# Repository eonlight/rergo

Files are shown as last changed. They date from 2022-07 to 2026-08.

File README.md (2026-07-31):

# rergo v4.0.3

Custom made keyboard using ergopad, ergogen and kicad

# V4

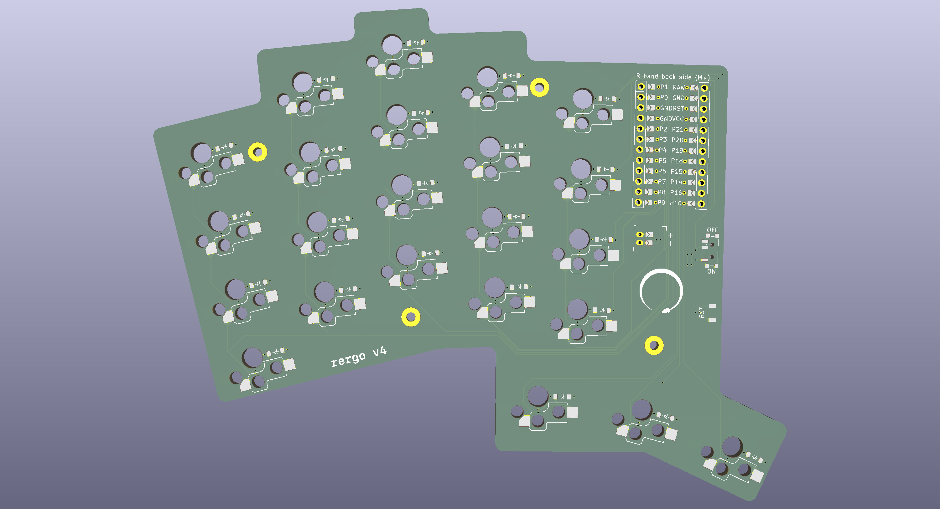
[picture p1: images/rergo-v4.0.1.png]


[rergo v4 design](/designs/v4/)

[rergo v4 kicad](/kicad/v4/)

[rergo v4 zmk config](/zmk-config/v4/)

# V3

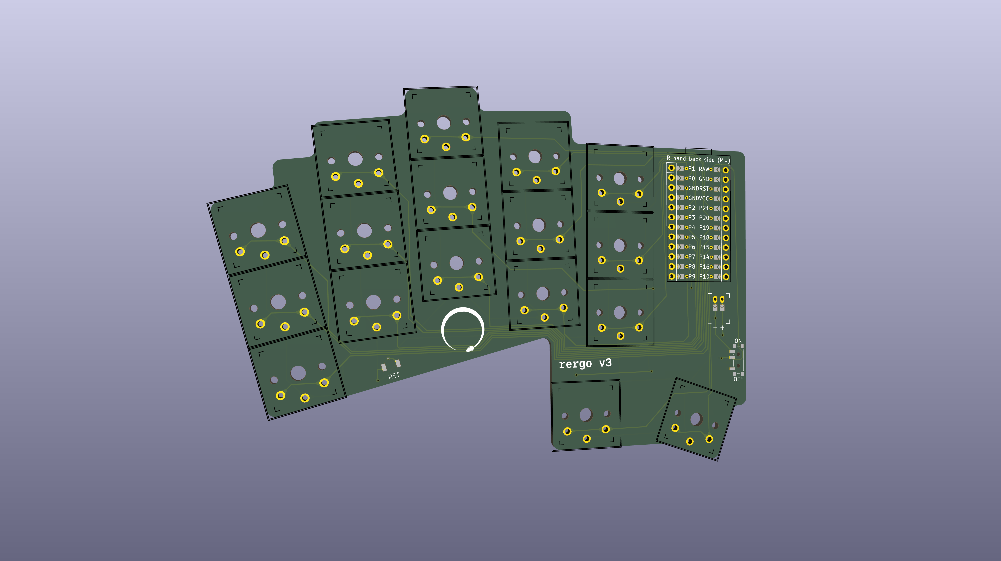
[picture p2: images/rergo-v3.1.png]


[rergo v3 design](/designs/v3/)

[rergo v3 kicad](/kicad/v3/)

[rergo v3 zmk config](/zmk-config/v3/)

# V2

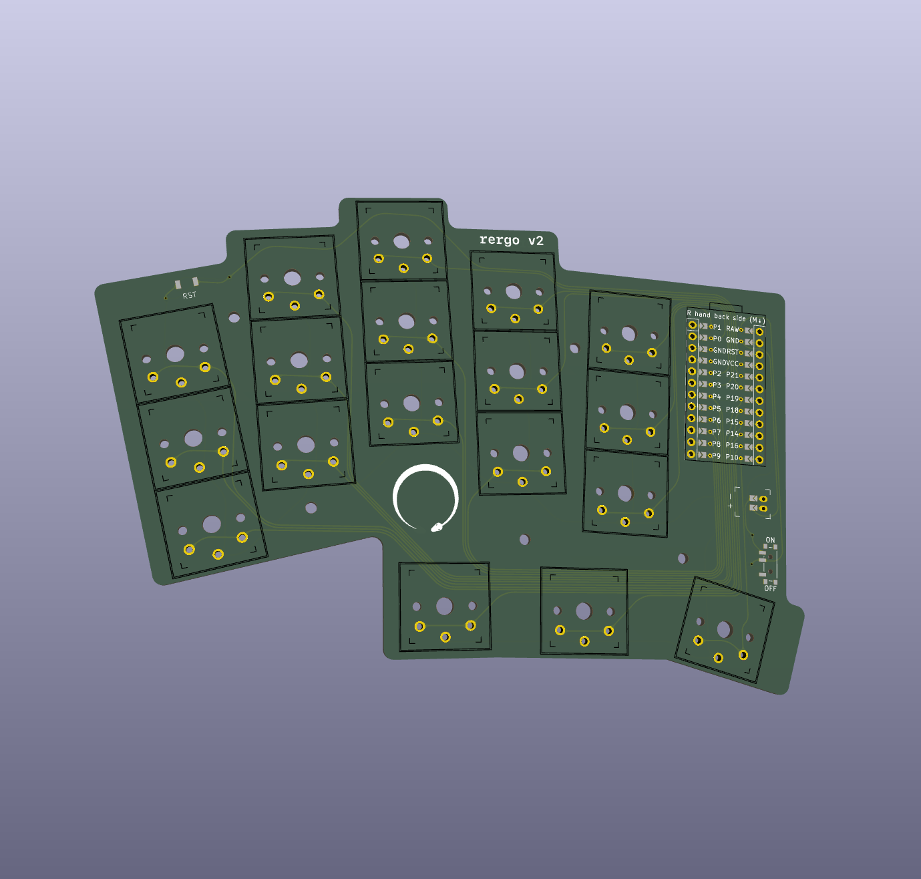
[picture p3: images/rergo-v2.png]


[rergo v2 design](/designs/v2/)

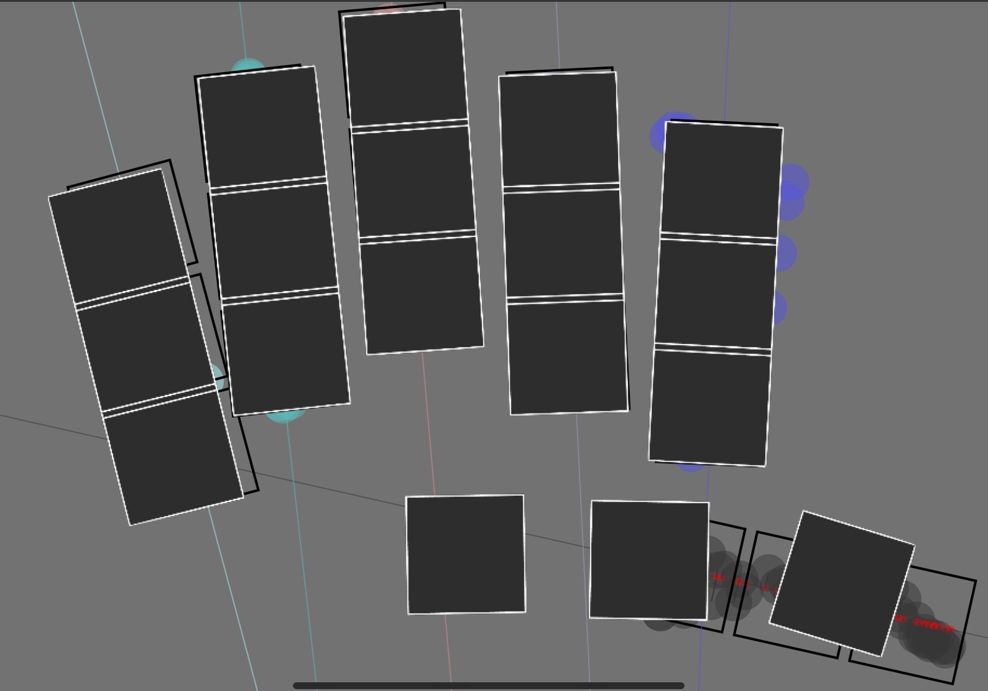
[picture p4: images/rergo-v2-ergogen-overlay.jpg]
ergopad and ergogen overlay


# V1

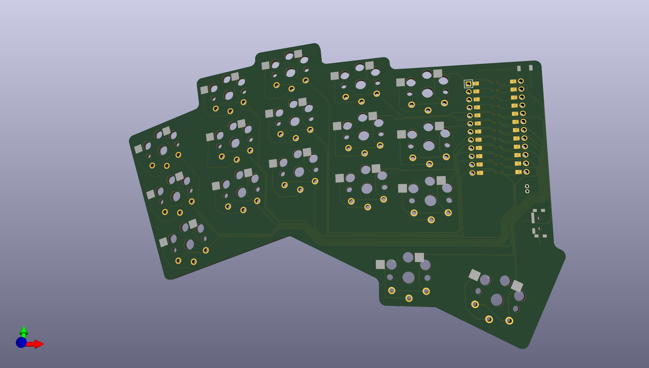
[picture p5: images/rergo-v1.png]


[rergo v1 design](/designs/v1/)

### Firmware (ZMK)

The keyboard runs [ZMK](https://zmk.dev). v4 firmware lives in its own repo (`zmk-config`); earlier versions are under [/zmk-config/v3/](/zmk-config/v3/). It builds a custom out-of-tree shield `rergo` for the **nice_nano v2**, split left/right.

* **Docker image must match ZMK's Zephyr version.** ZMK `main` pulls Zephyr 4.1, which needs Zephyr SDK 0.16/0.17 → use `zmkfirmware/zmk-build-arm:4.1-branch`. The `4.4-branch` image (SDK 1.0.1) is incompatible and will not build.
* First-time setup (fetches ~2GB into gitignored dirs): from the config repo root,
    ```
    docker run --rm -v"$(pwd)":/tmp/zmk-config -w /tmp/zmk-config zmkfirmware/zmk-build-arm:4.1-branch \
      bash -c 'west update && west zephyr-export'
    ```
* Build a target (`rergo_left` / `rergo_right` / `settings_reset`; see `build.yaml`). Run `west zephyr-export` again in the same container — it does not persist across `docker run`:
    ```
    docker run --rm -v"$(pwd)":/tmp/zmk-config -w /tmp/zmk-config zmkfirmware/zmk-build-arm:4.1-branch bash -c '
      west zephyr-export >/dev/null 2>&1
      west build -s zmk/app -d build/left -b "nice_nano//zmk" -S studio-rpc-usb-uart -- \
        -DSHIELD=rergo_left -DZMK_CONFIG=/tmp/zmk-config/config \
        -DZMK_EXTRA_MODULES=/tmp/zmk-config -DCONFIG_ZMK_STUDIO=y'
    ```
    Output is `build/<target>/zephyr/zmk.uf2`. Flash by double-tapping reset and copying the `.uf2` to the `NICENANO` USB drive.
* **Left half is central** (USB + ZMK Studio); right half is a BLE peripheral. Flash the matching `.uf2` to each.
* `settings_reset.uf2` clears stored BLE bonds — flash to both halves if pairing gets stuck, then reflash the normal firmware.

### Testing / bring-up

You do **not** need every diode and switch soldered to test a key — each key is an independent path (`col → switch → diode → row`). Test with only the nice_nano + that key's diode soldered; **bridge the switch pads with tweezers** to simulate a press.

Order of operations:
1. **Before soldering the nice_nano**: continuity-check every diode's orientation (see Diode Notes — cathode/`|` toward the row).
2. **Solder + flash the nice_nano**, then confirm the left half enumerates over USB (types characters / shows up in [ZMK Studio](https://studio.zmk.dev), enabled in this firmware).
3. **Walk the matrix**: short each key's pads with tweezers and watch the character appear in a text editor or key highlight in ZMK Studio. A key that never registers → recheck that key's diode joint and its col/row solder.
4. Only after the whole matrix reads correctly, solder the switches. Repeat for the right half (flash `rergo_right.uf2`, or pair it to the left and test via Studio).

Multimeter checks (power off):
* Use **diode mode** (not plain continuity) when a diode is in the path — `col2row` means it conducts col → row only. Red on the col pad, black on the row pad → ~0.5–0.7 V when pressed, open when released; reversed probes stay open (confirms diode direction).
* Plain continuity: switch pad ↔ its nice_nano pin pad (catches cold joints); adjacent col/row pins should **not** be connected when idle (catches bridges).
* **Use the pads on the other side of the soldered components to test things (diode/socket)**
* shorting the pads on the other side should produce a key
* **THE LIKELY PROBLEM IS THE DIODE!!!!**

Deeper firmware debugging: add `CONFIG_ZMK_USB_LOGGING=y` to `config/rergo.conf`, rebuild, and open the USB serial port to see raw key press/release events with position numbers (turn it off for daily use — it raises power draw).

#### Chatter (one press prints multiple characters)

**Check the hotswap socket joints first — that was the cause on v4.** A socket that looks soldered but isn't fully wetted makes intermittent contact, which the firmware reads as release + re-press. Reflowing the socket fixed it. Other hardware suspects: cold joint on that key's diode, or debris/wear in the switch.

To tell hardware from timing: move the switch to another socket. If the chatter follows the switch it's the switch; if it stays with the position it's the board (socket or diode joint).

Debounce tuning masks bounce but does not fix a bad joint — only reach for it once the joints are known good, or if chatter is spread evenly across many keys. The `kscan` node's defaults are 5 ms press / 5 ms release; raising **release** targets repeats without adding keystroke latency (v4 uses `debounce-release-ms = <15>`). To experiment without touching the devicetree, put `CONFIG_ZMK_KSCAN_DEBOUNCE_RELEASE_MS=25` in `config/rergo.conf` — it overrides all kscan instances. Above ~30 ms rapid double-taps start getting swallowed.

#### Firmware gotchas hit during v4 bring-up

* **No key on either half registers, but the board flashes, boots and pairs fine** → the shield is missing `chosen { zmk,kscan = &kscan0; };`. Defining the matrix node is not enough; without the `chosen` entry ZMK builds cleanly with no key scanner at all and warns about nothing.
* Every keymap layer must have **exactly one binding per key position** (46 on v4). A miscount produces only an "excess elements in array initializer" warning at build time, but silently shifts every following key on that layer.

### KiCad Notes

`x` to start routing

`v` to create via when routing

`Round Tracks` plugin to round traces (**some traces might require deleting and redoing and re applying the plugin**)

`Edit > Edit Teardrops > Apply` to create teardrops on vias (**might also require some re doing of tracks and re applying of teardrop**)

`ctr + tab` changes the views (back vs. front layers)

### Soldering notes

* remember to bridge the pads under the nice-nano with solder
* connections can be checked with a multi-meter to verify pads have been soldered properly
* battery connector pads also need to be bridged, but these will be on the other side of the board

#### Diode Notes

POS ->|- GND

- Ground should face where the `|` is
- Measure with multimeter using continuity tool
    - Voltage will drop when direction is found
- Current diode choice will have:
    - lettering at the top (right side up) when Ground is on the left
    - lettering at the bottom (up side down) when Ground is on the right
    - Left Side Half: Diodes with lettering facing up
    - Right Side Half: Diode with lettering facing down
    - Diodes go at the bottom of the board

### PCB manufacturing notes

* File > Fabrication Outputs > Gerbers
* F&B: Cu, Paste, Silkscreen, Mask and Edge.Cuts
Output Folder: gerber
* Generate Drill Files... > Generate
* Plot

### Desoldering notes
- add solder to the iron
- hold the keyboard between legs
- use fingernail to press on the middle of the keyswitch whilst heating up both prongs, one after the other
- once the switch is loose, change the grip to hold the switch on both sides
- heat both prongs 1 at the time whilst wiggle switch out
- to clean switch, use solder wick
    - heat the prong next to the wick and slide the prong out of the wick
- Extra Notes
    - if prong seems stuck, add more solder
    - drop the switch as soon as it's out, it's REALLY hot, you'll get burnt

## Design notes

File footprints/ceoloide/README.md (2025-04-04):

# @ceoloide's ergogen PCB footprints

> [!WARNING]
> These footprints have only been partially tested and are still under active development. Use them at your own risk.

1. [How to use these footprints in Ergogen](#how-to-use-these-footprints-in-ergogen)
1. [Installation](#installation)
    1. [How to add the footprints as a local git submodule](#how-to-add-the-footprints-as-a-local-git-submodule)
    1. [How to add the footprints as a GitHub Codespaces git submodule](#how-to-add-the-footprints-as-a-github-codespaces-git-submodule)
    1. [How to use the footprints in your ergogen config](#how-to-use-the-footprints-in-your-ergogen-config)
    1. [How to clone your ergogen repo](#how-to-clone-your-ergogen-repo)
    1. [How to update footprints dependencies](#how-to-update-footprints-dependencies)
    1. [How to remove footprints dependencies](#how-to-remove-footprints-dependencies)
1. [How to design or modify ergogen footprints](#how-to-design-or-modify-ergogen-footprints)
1. [Licenses and recognition](#licenses-and-recognition)

## How to use these footprints in Ergogen

> [!WARNING]
> These footprints have been upgraded to KiCad 8 and are only compatible with Ergogen v4.1.0 and above. Make sure to set the `template: kicad8` option in each PCB definition:

```yaml
meta:
  engine: 4.1.0 # Min Ergogen version for KiCad 8 footprints
[...]
pcbs:
  main_pcb:
    template: kicad8 # Required, since footprints are KiCad 8 only
    outlines:
      [...]
    footprints:
      [...]
```

> [!NOTE]
> You can directly use these custom footprints in the experimental GUI at [ergogen.ceoloide.com](https://ergogen.ceoloide.com). Just refer to them as `ceoloide/[footprint_filename]`, for example: `ceoloide/switch_mx`.

Using custom footprints with a local Ergogen setup is relatively straightforward. You can follow the steps outlined in [this amazing guide](https://flatfootfox.com/ergogen-part4-footprints-cases/) if you want an easy tutorial.

If you are already comfortable running Ergogen locally, you just need to:

1. rename your Ergogen YAML file to `config.yaml`,
1. create a `footprints` folder alongside it
1. clone this repo into the `footprints` folder using a folder name of your choice (see instructions below)
1. now run Ergogen by passing a folder instead of a YAML file, for example `ergogen .`

## Installation

### How to add the footprints as a local git submodule

> [!WARNING]
> If you are using GitHub Codespaces, skip the following instructions and go to the next section.

If you have git setup on your local environment with SSH credentials, you can add the library as a
git submodule. To use custom footprint, ergogen requires them to be located under a folder named
`footprints` placed alongside a `config.yaml` file containing the board definition.

Assuming the above files are located at `./ergogen` from the git folder root, then you can use this
command to add the footprints into a `ceoloide` folder in the right location:

```bash
git submodule add git@github.com:ceoloide/ergogen-footprints.git ergogen/footprints/ceoloide
```

Note that you can customize `ceoloide` to be whatever name you choose. Just make sure to refer to the custom
name in your YAML file.

### How to add the footprints as a GitHub Codespaces git submodule

Due to the limitations on how GitHub Codespaces handle submodules, use this command instead of the one above:

```bash
git submodule add https://github.com/ceoloide/ergogen-footprints.git ergogen/footprints/ceoloide
```

### How to use the footprints in your ergogen config

Assuming you used `ergogen/footprints/ceoloide` as the destination folder for the submodule, you will be able
to refer to any footprint contained in that folder as `ceoloide/[footprint_filename]`, which would look something like this:

```yaml
meta:
  engine: 4.1.0 # Min Ergogen version for KiCad 8 footprints
[...]
pcbs:
  your_keyboard:
    template: kicad8 # Required, since footprints are KiCad 8 only
    outlines:
      [...]
    footprints:
      nice_nano:
        what: ceoloide/switch_mx
        [...]
```

### How to clone your ergogen repo

Users who clone your ergogen repo, must also include the submodule. So you should instruct them to clone with `--recursive` mode:

```bash
git clone --recursive git@github.com:your-user/your-keyboard.git
```

Alternative they can init and update the submodules in a repo that was already cloned without the `--recursive` argument:

```bash
git submodule update --init --recursive --remote
```

### How to update footprints dependencies

When you add a submodule, it won't automatically be updated, meaning that you will maintain files as long as you don't take specific actions. This is great to avoid having to deal with unforseen changes in the source.

Should you however want to update your footprint dependencies, you can run the following command:

```bash
git submodule update --recursive --remote
```

This will fetch and checkout the latest commits in the source repo and pull the files so they are available.

Be aware that you will need to commit the submodule update change, or it will revert with a subsequent pull. To do so you can run these commands:

```bash
# First add the updated submodule to the staged files
git add ergogen/footprints/ceoloide
# Then commit the staged files to persist the update
git commit -m "Update footprint submodule"
```

### How to remove footprints dependencies

If you do not longer need the footprint submodule and want to remove it from your repository, you can simply run this command:

```bash
git rm ergogen/footprints/ceoloide
```

This will update the `.gitmodules` file to remove the submodule reference and remove the submodule directory. Make sure to commit and push the
change for it to be persisted and propagated, or it will revert with a subsequent pull:

```bash
git commit -m "Remove footprint submodule"
```

## How to design or modify ergogen footprints

[@infused-kim](https://github.com/infused-kim) wrote a [guide on how to convert KiCad footprints to ergogen](https://www.notion.so/nilnil/Convert-Kicad-Footprint-to-Ergogen-8340ce87ad554c69af4e3f92bc9a0898?pvs=4), which
has been extensively used to create original ergogen footprints in this repository.

## Licenses and recognition

All original footprints and those copied from [@MrZealot](https://github.com/mrzealot), [@TildeWill](https://github.com/tildewill), and [@virginia2244](https://github.com/virginia2244) are licensed under [MIT License][mit]. I also extensively used and modified footprints created by [@infused-kim](https://github.com/infused-kim), which are licensed under [Creative Commons Attribution-NonCommercial-ShareAlike 4.0 International License][cc-by-nc-sa].

[][cc-by-nc-sa]

Furthermore, all of the work I've done wouldn't have been possible without the inspiration or direct reference to the work done by:

- [@foostan](https://github.com/foostan) for the original [Corne keyboard](https://github.com/foostan/crkbd)
- [@flatfootfox](https://github.com/flatfootfox) for the [Ergogen v4 introductory articles](https://flatfootfox.com/ergogen-introduction/)
- [@infused-kim](https://github.com/infused-kim) for the [amazing work done with the footprints](https://github.com/infused-kim/kb_ergogen_fp) I ~stole from~ got inspired by
- [@MrZealot](https://github.com/mrzealot) / [@ergogen](https://github.com/ergogen) for the [amazing tool](https://github.com/ergogen/ergogen) and [amazing community](https://discord.gg/Tj2TUaUW)
- [@virginia2244](https://github.com/virginia2244) for the [incredible work on MCU footprints](https://github.com/Virginia2244/ergogen_footprints)
- [@benvallack](https://github.com/benvallack) for the [great video content on YouTube](https://www.youtube.com/watch?v=UKfeJrRIcxw) and getting me started on the Ergogen journey

[mit]: https://opensource.org/license/mit/
[cc-by-nc-sa]: http://creativecommons.org/licenses/by-nc-sa/4.0/
[cc-by-nc-sa-image]: https://licensebuttons.net/l/by-nc-sa/4.0/88x31.png

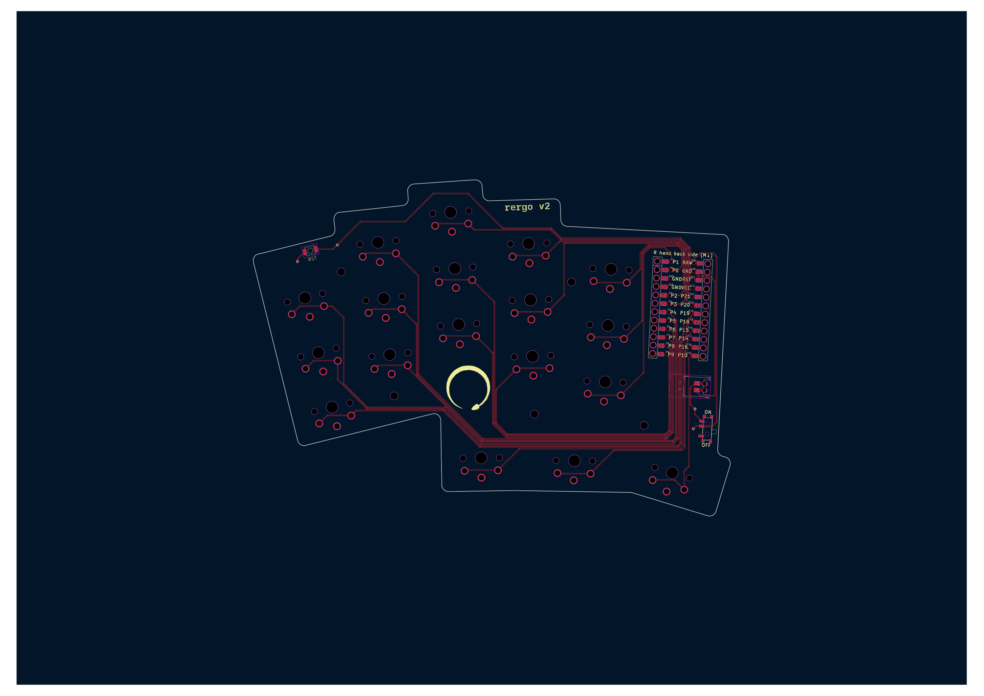
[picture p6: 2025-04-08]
images/rergo-v2-kicad.png

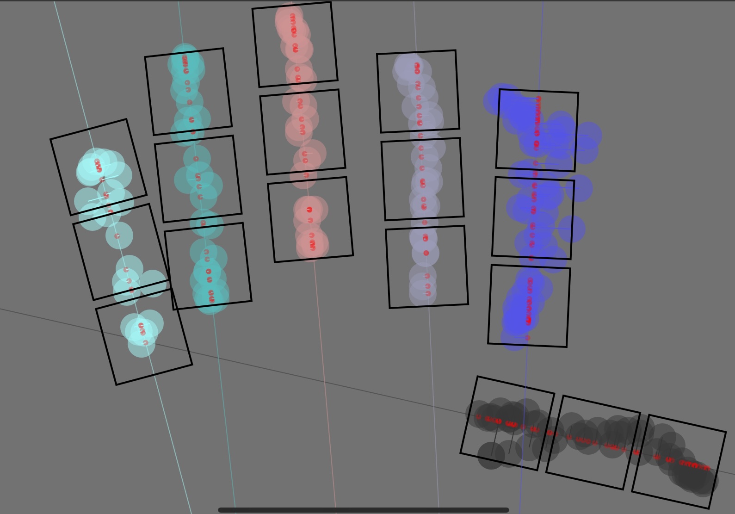
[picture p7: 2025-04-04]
images/rergo-v2-ergopad.jpg

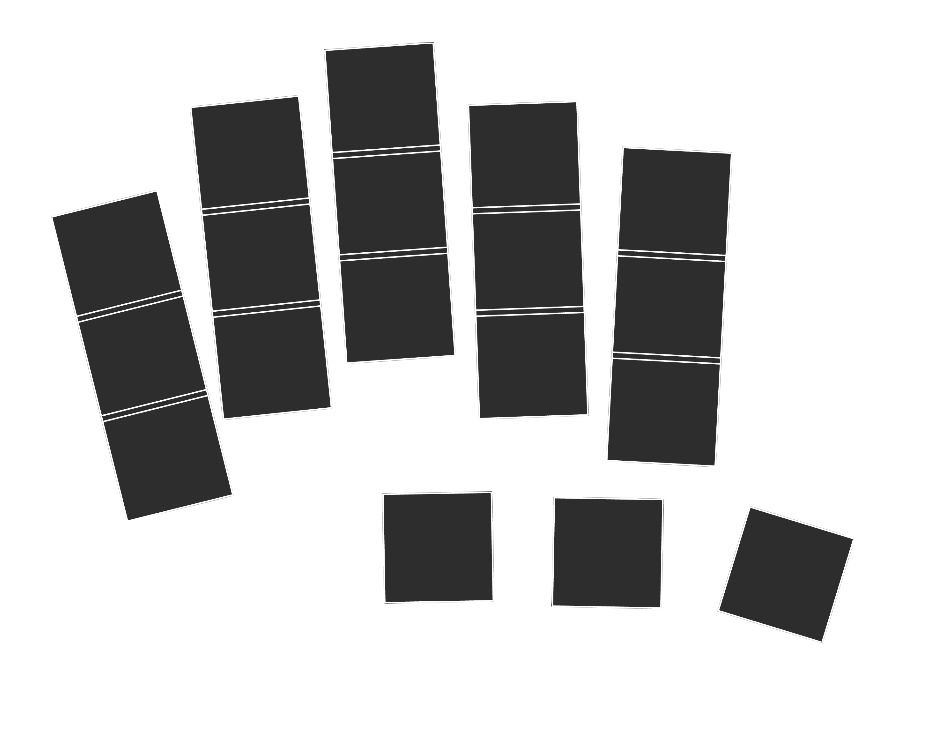
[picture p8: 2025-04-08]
images/rergo-v2-ergogen.png

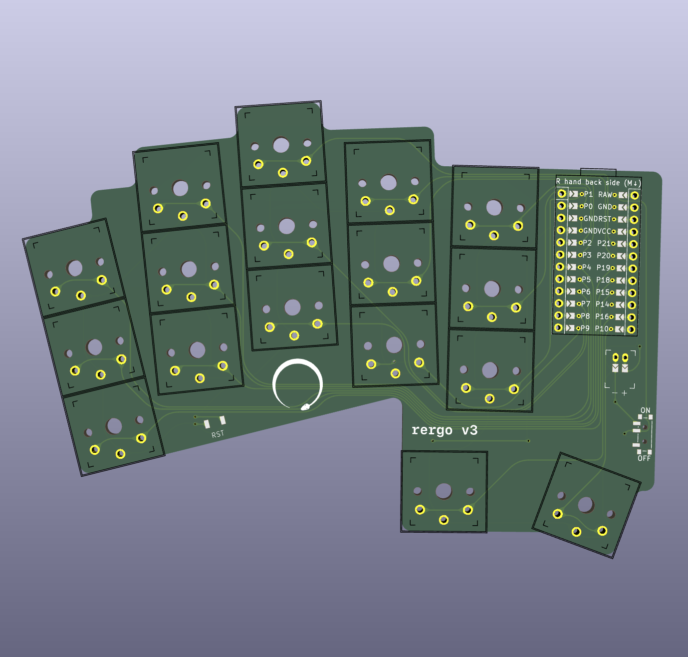
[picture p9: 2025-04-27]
images/rergo-v3.png

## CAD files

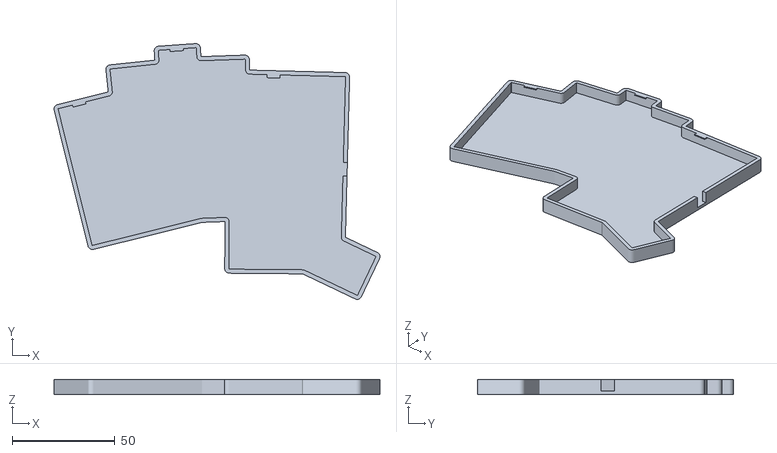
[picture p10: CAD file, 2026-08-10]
cases/v4/tent_case.stl
158.4 x 124.3 x 7.12

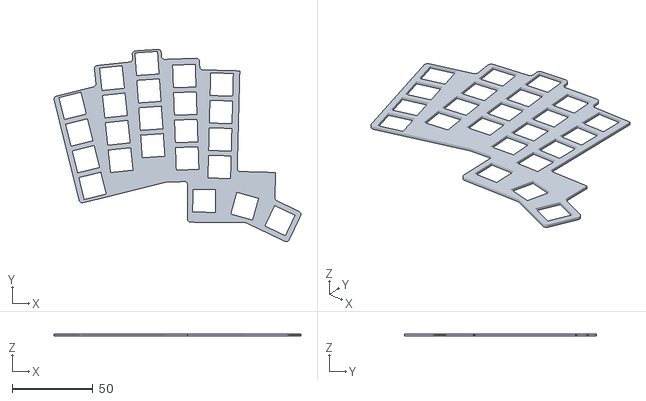
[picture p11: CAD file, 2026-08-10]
cases/v4/plate.stl
152.8 x 119.0 x 1.50

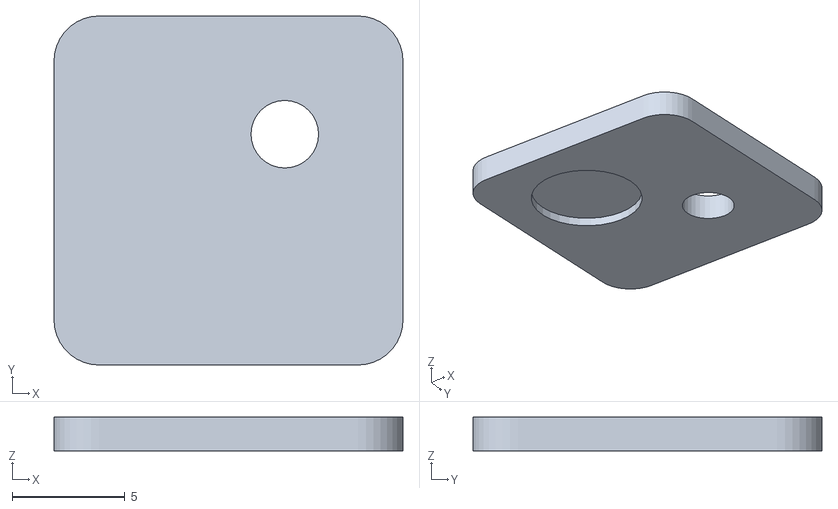
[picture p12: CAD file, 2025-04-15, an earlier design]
cases/v0/bottom.stl
15.5 x 15.5 x 1.50

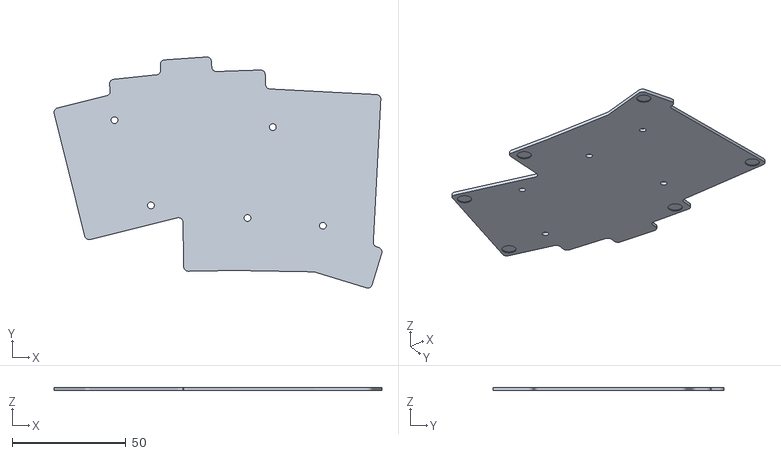
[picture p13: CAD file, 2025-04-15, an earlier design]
cases/v2/bottom.stl
144.0 x 101.4 x 1.50

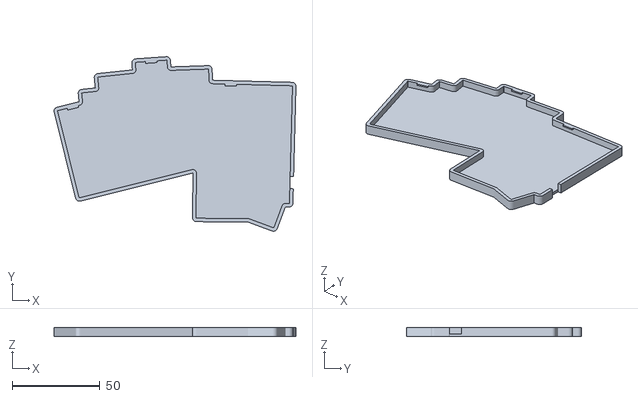
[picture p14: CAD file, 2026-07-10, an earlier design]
cases/v3/bottom_case.stl
137.6 x 99.3 x 5.25

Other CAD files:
cases/v4/bottom_case.stl

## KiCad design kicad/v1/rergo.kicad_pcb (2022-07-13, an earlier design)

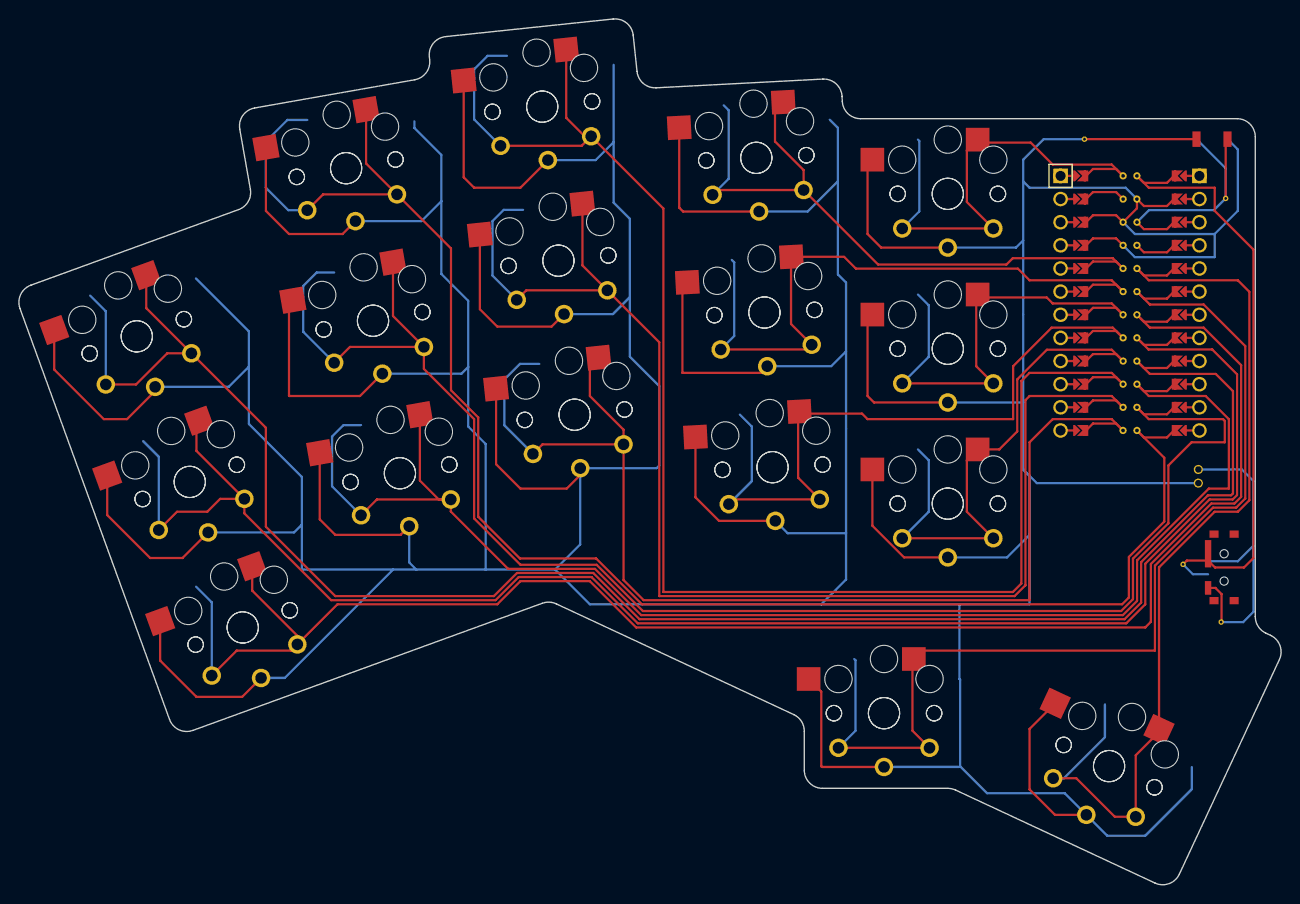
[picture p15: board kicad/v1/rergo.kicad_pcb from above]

Board: 2 copper layers, 138.5 x 95.0 mm, 35 parts (0 on the bottom side), 18 nets.

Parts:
MCU1: ProMicro
S1, S2, S3, S4, S5, S6, S7, S8, S9, S10, S11, S12, S13, S14, S15, S16, S17, S18, S19, S20, S21, S22, S23, S24, S25, S26, S27, S28, S29, S30, S31, S32, S33, S34: PG1350

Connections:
GND: MCU1.2, MCU1.21, MCU1.22, S1.2, S2.2, S3.2, S4.2, S5.2, S6.2, S7.2, S8.2, S9.2, S10.2, S11.2, S12.2, S13.2, S14.2, S15.2, S16.2, S17.2, S18.2, S19.2, S20.2, S21.2, S22.2, S23.2, S24.2, S25.2, S26.2, S27.2, S28.2, S29.2, S30.2, S31.2, S32.2, S33.2, S34.2
P1: MCU1.24, S29.1, S30.1
P2: MCU1.20, S23.1, S24.1
P3: MCU1.19, S21.1, S22.1
P4: MCU1.18, S27.1, S28.1
P5: MCU1.17, S19.1, S20.1
P6: MCU1.16, S25.1, S26.1
P7: MCU1.15, S17.1, S18.1
P8: MCU1.14, S15.1, S16.1
P9: MCU1.13, S13.1, S14.1
P10: MCU1.12, S11.1, S12.1
P14: MCU1.10, S7.1, S8.1
P15: MCU1.9, S5.1, S6.1
P16: MCU1.11, S9.1, S10.1
P18: MCU1.8, S3.1, S4.1
P19: MCU1.7, S1.1, S2.1
P20: MCU1.6, S31.1, S32.1
P21: MCU1.5, S33.1, S34.1

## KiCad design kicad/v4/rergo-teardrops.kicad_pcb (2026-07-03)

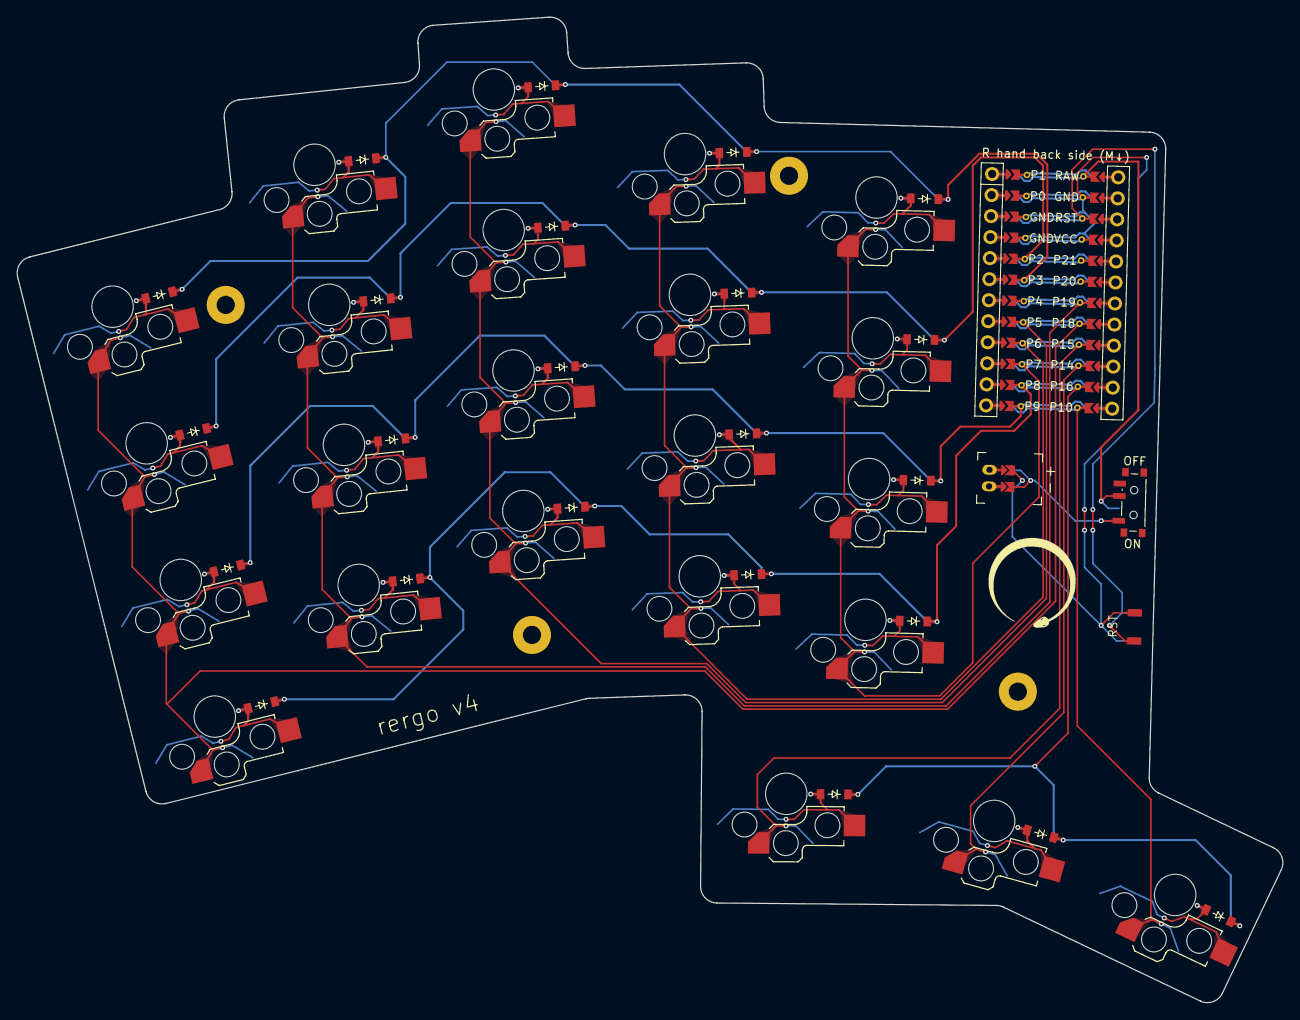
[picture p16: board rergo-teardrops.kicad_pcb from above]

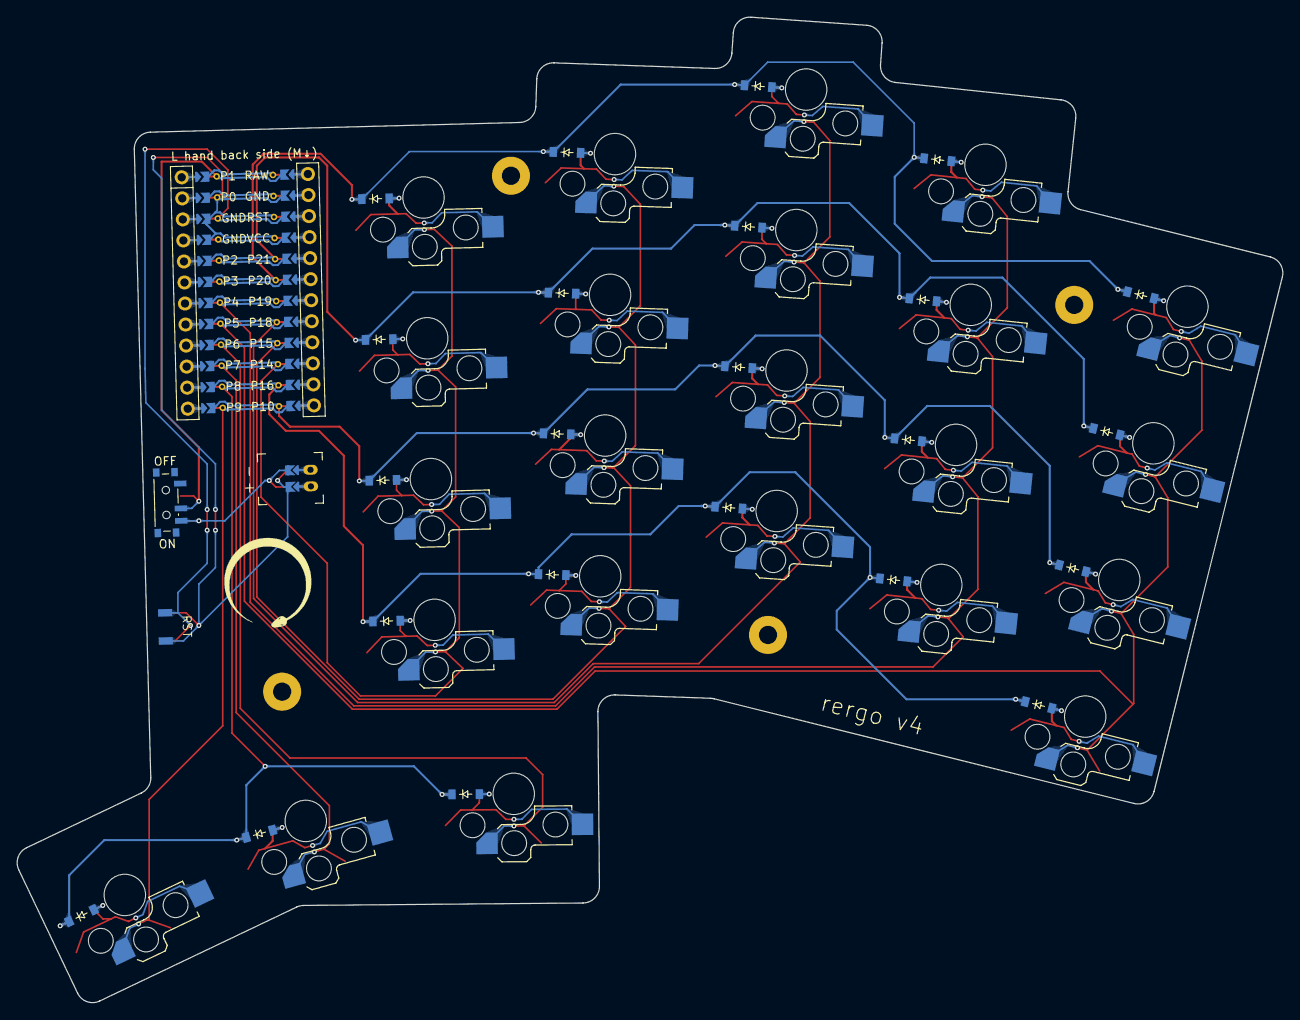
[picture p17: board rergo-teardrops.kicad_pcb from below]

Board: 2 copper layers, 152.8 x 119.0 mm, 55 parts (23 on the bottom side), 42 nets.

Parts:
D1, D2, D3, D4, D5, D6, D7, D8, D9, D10, D11, D12, D13, D14, D15, D16, D17, D18, D19, D20, D21, D22, D23: diode_tht_sod123
JST1: battery_connector_jst_ph_2
LOGO1: rergo logo
MCU1: mcu_nice_nano
MH1, MH2, MH3, MH4: mounting_hole_npth
PWR1: power_switch_smd_side
RST1: reset_switch_b3u_1000p
S1, S2, S3, S4, S5, S6, S7, S8, S9, S10, S11, S12, S13, S14, S15, S16, S17, S18, S19, S20, S21, S22, S23: switch_choc_v1_v2

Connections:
GND: JST1.2, MCU1.102, MCU1.121, MCU1.122, RST1.2
JST1_1: JST1.11, JST1.21, JST1.31
JST1_2: JST1.12, JST1.22, JST1.32
P2: D3.1, D7.1, D11.1, D15.1, D19.1, MCU1.120
P3: D4.1, D8.1, D12.1, D16.1, D20.1, MCU1.119
P5: MCU1.117, S9.1, S10.1, S11.1, S12.1
P6: MCU1.116, S13.1, S14.1, S15.1, S16.1
P7: MCU1.115, S17.1, S18.1, S19.1, S20.1
P8: D1.1, D5.1, D9.1, D13.1, D17.1, MCU1.114
P9: D2.1, D6.1, D10.1, D14.1, D18.1, MCU1.113
P10: MCU1.112, S23.1
P14: MCU1.110, S22.1
P15: MCU1.109, S21.1
P16: D21.1, D22.1, D23.1, MCU1.111
P18: MCU1.108, S1.1, S2.1, S3.1, S4.1
P19: MCU1.107, S5.1, S6.1, S7.1, S8.1
RAW: MCU1.101, PWR1.2
RST: MCU1.103, RST1.1
far_bottom: D17.2, S17.2
far_home: D18.2, S18.2
far_numbers: D20.2, S20.2
far_top: D19.2, S19.2
home_single: D22.2, S22.2
index_bottom: D13.2, S13.2
index_home: D14.2, S14.2
index_numbers: D16.2, S16.2
index_top: D15.2, S15.2
inner_single: D21.2, S21.2
middle_bottom: D9.2, S9.2
middle_home: D10.2, S10.2
middle_numbers: D12.2, S12.2
middle_top: D11.2, S11.2
outer_single: D23.2, S23.2
pinky_bottom: D1.2, S1.2
pinky_home: D2.2, S2.2
pinky_numbers: D4.2, S4.2
pinky_top: D3.2, S3.2
pos: JST1.1, PWR1.1, PWR1.3
ring_bottom: D5.2, S5.2
ring_home: D6.2, S6.2
ring_numbers: D8.2, S8.2
ring_top: D7.2, S7.2

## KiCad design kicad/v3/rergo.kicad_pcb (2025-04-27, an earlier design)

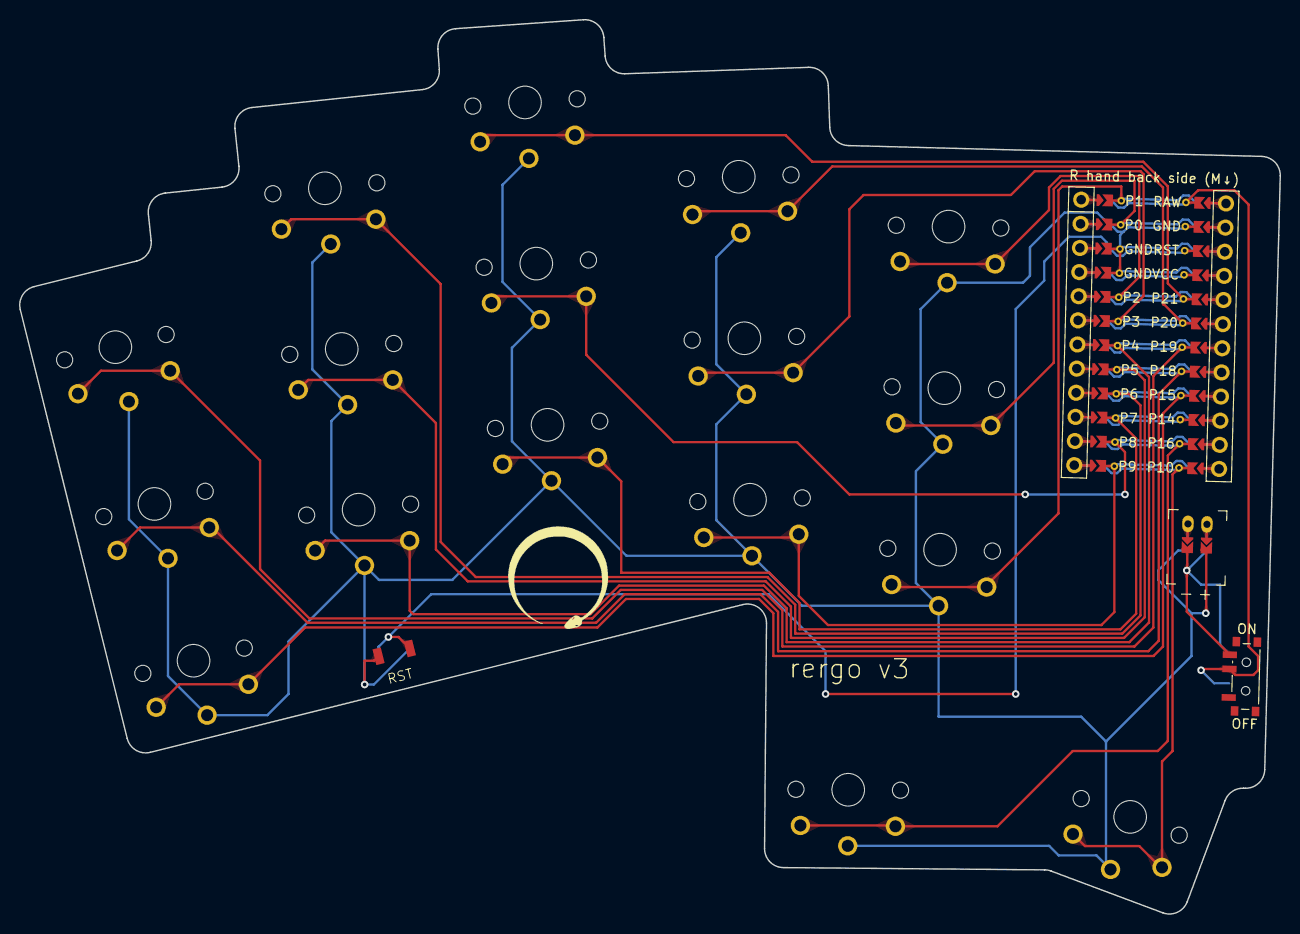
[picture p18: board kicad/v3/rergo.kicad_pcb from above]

Board: 2 copper layers, 132.6 x 94.1 mm, 22 parts (0 on the bottom side), 23 nets.

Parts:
JST1: battery_connector_jst_ph_2
LOGO1: rergo logo
MCU1: mcu_nice_nano
PWR1: power_switch_smd_side
RST1: reset_switch_b3u_1000p
S1, S2, S3, S4, S5, S6, S7, S8, S9, S10, S11, S12, S13, S14, S15, S16, S17: PG1350

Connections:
GND: JST1.2, MCU1.102, MCU1.121, MCU1.122, RST1.2, S1.2, S2.2, S3.2, S4.2, S5.2, S6.2, S7.2, S8.2, S9.2, S10.2, S11.2, S12.2, S13.2, S14.2, S15.2, S16.2, S17.2
JST1_1: JST1.11, JST1.21, JST1.31
JST1_2: JST1.12, JST1.22, JST1.32
P0: MCU1.123, S14.1
P1: MCU1.124, S13.1
P2: MCU1.120, S15.1
P3: MCU1.119, S11.1
P4: MCU1.118, S4.1
P5: MCU1.117, S5.1
P6: MCU1.116, S6.1
P7: MCU1.115, S7.1
P8: MCU1.114, S8.1
P9: MCU1.113, S10.1
P10: MCU1.112, S17.1
P15: MCU1.109, S1.1
P16: MCU1.111, S16.1
P18: MCU1.108, S2.1
P19: MCU1.107, S3.1
P20: MCU1.106, S12.1
P21: MCU1.105, S9.1
RAW: MCU1.101, PWR1.2
RST: MCU1.103, RST1.1
pos: JST1.1, PWR1.1, PWR1.3

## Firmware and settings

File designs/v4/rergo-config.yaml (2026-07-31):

meta:
  version: v4.0.5
  name: rergo
  author: rdc

units:
  SS: 1.5 # screw size
  FR: 4.1 # feet radius: 3.2mm / 3.8mm for new feet
  CH: 1.5 # case height: 1.5mm
  PH: 1.5 # plate height: 1.5mm
  WH: CH*4.75 # wall height: 7.125mm
  FI: 0.5 # feet indentation: 0.5mm
  SR: 4.6/2 # screw head radius: 4.6/2 = 2.15mm
  SH: 2.2/2 # screw hole radius: 2.2/2 = 1.1mm

points:
  key.padding: cy
  zones:
    main:
      anchor.shift: [150, -150]  # Fix placement on KiCAD sheet
      anchor.rotate: 14
      key.spread: cx
      rows:
        bottom.row_net: P8
        home.row_net: P9
        top.row_net: P2
        numbers.row_net: P3
      columns:
        pinky:
          key.col_net: P18
          rows.bottom.bind: [2, 55, 0.5, 1.5] # u r d l
          rows.home.bind: [2, 0, 0, 1.5] # u r d l
          rows.top.bind: [2, 0, 0, 1.5] # u r d l
          rows.numbers.bind: [0, 15, 0, 1.5] # u r d l
        ring:
          key.col_net: P19
          key.splay: -8
          key.stagger: cy * 0.66
          key.spread: cx * 1.15
          rows.numbers.bind: [0.5, 6, 0, 1.5] # u r d l
        middle:
          key.col_net: P5
          key.splay: -2
          key.stagger: cy * 0.4
          key.spread: cx * 1.15
          rows.bottom.bind: [5, 0, 5, 0] # u r d l
          rows.numbers.bind: [0, 0.5, 0, 0] # u r d l
        index:
          key.col_net: P6
          key.splay: -2
          key.stagger: cy * -0.55
          key.spread: cx * 1.15
          rows.numbers.bind: [2.5, 1, 1, 5] # u r d l
          rows.bottom.bind: [0, 0, 6, 10] # u r d l
        far:
          key.col_net: P7
          key.splay: -3.5
          key.stagger: cy * -0.35
          key.spread: cx * 1.1
          rows.numbers.bind: [0.5, 26, 67, 5] # u r d l
    thumb:
      anchor:
        ref: main_far_bottom
        shift: [cx * -0.5 , cy * -1.25]
        rotate: -4
      rows.single.row_net: P16
      columns:
        inner:
          key.col_net: P15
          key.rotate: 5
          rows.single.bind: [20, 20, 5, 1.5] # u r d l
        home:
          key.col_net: P14
          key.rotate: -10
          key.shift: [cx * 0.35, cy * -0.05]
          rows.single.bind: [9, 0, 0, 20] # u r d l
        outer:
          key.col_net: P10
          key.rotate: -20
          key.shift: [cx * 0.55, cy * -0.45]
          rows.single.bind: [2, 1.5, 2, 20] # u r d l
    screw_1:
      key.tags:
        - helper
        - screws
      anchor:
        aggregate.parts:
          - ref: main_pinky_numbers
          - ref: main_pinky_top
          - ref: main_ring_numbers
          - ref: main_ring_top
    screw_2:
      key.tags:
        - helper
        - screws
      anchor:
        aggregate.parts:
          - ref: main_middle_bottom
        shift: [0, -15]
    screw_3:
      key.tags:
        - helper
        - screws
      anchor:
        aggregate.parts:
          - ref: main_index_numbers
          - ref: main_far_numbers
        shift: [1, 0]
    screw_4:
      key.tags:
        - helper
        - screws
      anchor:
        aggregate.parts:
          - ref: thumb_home_single
          - ref: main_far_bottom
        shift: [10, 5]
outlines:
  _raw:
    - what: rectangle # main key outlines
      size: [cx - 0.5, cy - 0.5]
      bound: true
      where:
        - /main/
        - /thumb/
  cutout:
    - what: outline
      name: _raw
      fillet: 2
  keycaps:
    - what: rectangle
      size: [cx - 0.5, cy - 0.5]
      bound: false
      where:
        - /main/
        - /thumb/
  key_switch_cutout:
    - what: rectangle
      size: [14, 14]
      bound: false
      where:
        - /main/
        - /thumb/
  power_switch:
    - what: rectangle
      size: [4, 6.5]
      where:
        ref: main_far_bottom
        shift: [32.0, 15]
  nicenano_v2:
    - what: rectangle
      size: [18, 33]
      where:
        ref: main_far_home
        shift: [21.5, 24.5]
    - what: rectangle
      size: [9, 2]
      where:
        ref: main_far_home
        shift: [21.5, 42]
  jstph:
    - what: rectangle
      size: [7.6, 6]
      where:
        ref: main_far_bottom
        shift: [16.5, 17.5]
  reset_switch:
    - what: rectangle
      size: [3, 2.5]
      where:
        ref: main_far_bottom
        shift: [32.5, 0]
        rotate: -90
  _screw_heads:
    - what: circle
      where: screws
      radius: SR
  _screw_holes:
    - what: circle
      where: screws
      radius: SH
  _inner_wall:
    - what: outline
      name: _raw
      expand: 0.25
      fillet: 2
  _outer_wall:
    - what: outline
      name: _raw
      expand: 2.25
  feet:
    - what: circle
      radius: FR
      where: main_pinky_numbers
      adjust:
        shift: [cx * -0.25, cy * 0.25]
    - what: circle
      radius: FR
      where: main_pinky_bottom
      adjust:
        shift: [cx * -0.25, cy * -0.25]
    - what: circle
      radius: FR
      where: main_middle_numbers
      adjust:
        shift: [cx * 0.25, cy * 0.25]
    - what: circle
      radius: FR
      where: main_far_top
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

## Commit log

2022-07-13 added images + kicad files
    [rergo.kicad_pcb, rergo.kicad_sch]
2025-04-04 initial v2 commit
    [rergo.kicad_pcb, rergo.kicad_sch]
2025-04-06 added binding, mounting holes, text, logo, kicad library for logo, better reset button footprint; removed choc hotswap; updated net points for keys
    [rergo-config.yaml]
2025-04-08 added cases and kicad files
    [plate.stl, rergo.dsn, rergo.kicad_pcb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]
2025-04-08 removed footprints library and updated pcb image and read me
2025-04-12 moved tempaltes and added feet recesses to bototm plate
    [bottom.stl, plate.stl]
2025-04-12 added test version config
    [bottom.stl]
2025-04-12 added kicad notes
2025-04-15 added zmk-config files
    [bottom.stl]
2025-04-27 updated v3 no round tracks + added gerber files
    [rergo.kicad_pcb]
2025-04-27 updated gerber files
    [rergo.kicad_pcb]
2026-07-03 v4 added
    [rergo-teardrops.kicad_pcb, rergo.kicad_pcb]
2026-07-10 added v3 case design
2026-07-10 added v3 case stl
    [bottom_case.stl]
2026-07-27 added v4 + some notes
    [bottom_case.stl, plate.stl, tent_case.stl]
2026-08-10 updated v4 cases + keymap
    [bottom_case.stl, plate.stl, tent_case.stl]
